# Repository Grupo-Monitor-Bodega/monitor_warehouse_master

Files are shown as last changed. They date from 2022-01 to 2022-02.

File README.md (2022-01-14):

# Sistemas Embebidos
# Monitor Warehouse

* Diego Chaparro

* Juan Diego Carrero

* Raúl Morales

Repositorio del proyecto de la asignatura "Sistemas Embebidos" de la Universidad Nacional de Colombia, sede Bogotá. Aquí encontrará el proyecto del monitor de bodega, con toda la documentación requerida y el diseño completo del mismo.

El proyecto consiste en un monitor que tomará los datos relacionados a la temperatura y humedad en una bodega, en la cual se almacenan granos de café. Para el correcto almacenamiento del café es necesario monitorear los niveles de humedad a los que este se encuentra expuesto, la cual a su vez tiene relación con la temperatura; con base a estos requerimientos, el café requiere que la humedad se encuentre establecida en un rango entre 10.3 y 11.3%, esta a su vez es afectada por las condiciones medioambientales a la que la bodega se encuentra expuesta. El tiempo que duran los bultos de café dentro de la bodega varía dependiendo del tipo, siendo este tiempo de algunos día e incluso puede alcanzar los 10 meses de almacenamiento, en los que se realizan ciertas rotaciones dentro de la bodega.

Se busca que el dispositivo final sea lo más pequeño posible con el fin de facilitar su portabilidad, por otra parte, se requiere que exista la posibilidad de realizar un monitoreo de forma remota y como requerimiento opcional, de realizar a su vez un historial sobre las dos variables a lo largo del tiempo para futuras mejoras en cuanto a la operación de la bodega.

Para la ejecución del proyecto, se realizará primeramente un prototipo funcional haciendo uso de un microcontrolador ESP32, de un sensor Shtc3 de humedad y temperatura, una pantalla lcd, así como de una protoboard y cables necesarios. Una vez el prototipo sea funcional, se realizarán los diseños para la PCB y la caja necesaria para la contención del producto y fácil accesibilidad para el cliente.

Con el fin de realizar alguna revisión posterior al hardware y software, se disponen de dos pines para propósito general.

Por último, en la sección de "Wiki", se amplía la información relacionada con el proyecto.

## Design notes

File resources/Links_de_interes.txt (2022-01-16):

Hoja de datos Sensor SHTC3
https://media.digikey.com/pdf/Data%20Sheets/Sensirion%20PDFs/HT_DS_SHTC3_D1.pdf

Hoja de datos Pantalla OLED 0.91" 128X32 SSD1306
http://www.buydisplay.com/download/manual/ER-OLED0.91-1_Series_Datasheet.pdf

Protocolo pantalla OLED
https://cdn-shop.adafruit.com/datasheets/SSD1306.pdf

Hoja de aplicación cargador batería
http://ww1.microchip.com/downloads/en/AppNotes/01149c.pdf

Aplicación TP4056
https://www.best-microcontroller-projects.com/tp4056.html#Using_3_Components_to_achieve_safe_charging

Hoja de datos módulo micro SD
http://datalogger.pbworks.com/w/file/fetch/89507207/Datalogger%20-%20SD%20Memory%20Reader%20Datasheet.pdf

Hoja de datos regulador LD1117
https://www.st.com/en/power-management/ldl1117.html

Hoja de datos Mosfet canal P BSS84P
https://www.electronicaplugandplay.com/component/edocman/?task=document.viewdoc&id=174&Itemid=

Hoja de datos Mosfet canal N BSS138
https://www.electronicaplugandplay.com/component/edocman/?task=document.viewdoc&id=85&Itemid=

Conexión para la medición del voltaje 
https://en.ovcharov.me/2020/02/29/how-to-measure-battery-level-with-esp32-microcontroller/

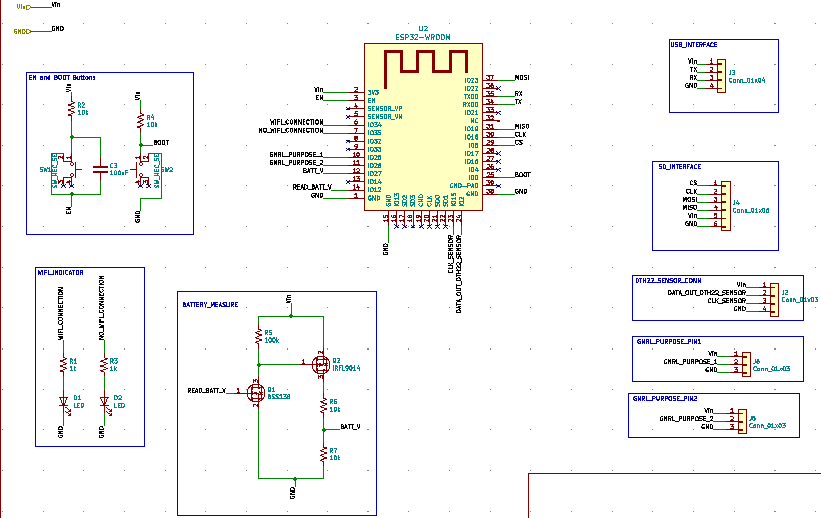
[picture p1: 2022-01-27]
resources/img/FinalSchematic1.png

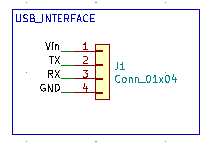
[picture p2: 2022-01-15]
resources/img/Schematic1.png

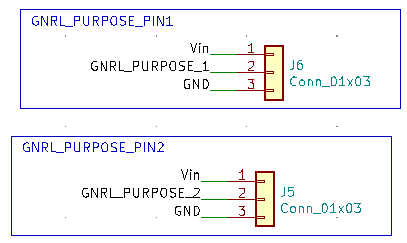
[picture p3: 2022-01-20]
resources/img/Schematic7.png

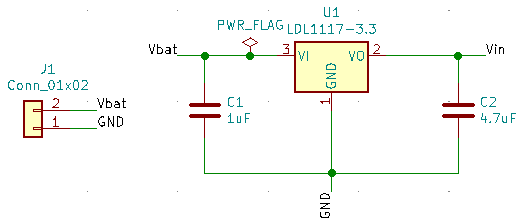
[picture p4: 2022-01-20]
resources/img/Schematic9.png

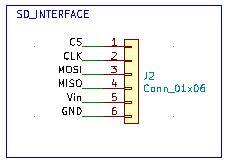
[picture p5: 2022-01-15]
resources/img/Schematic2.png

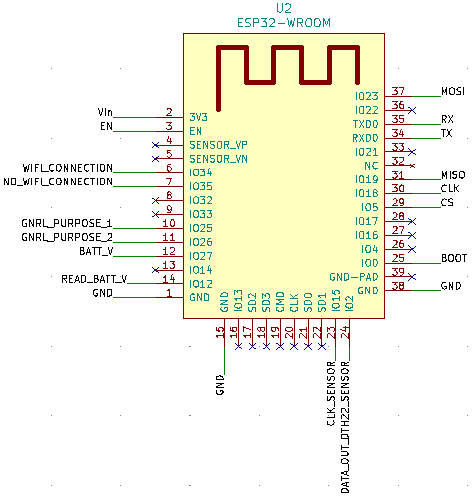
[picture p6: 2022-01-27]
resources/img/Schematic6.png

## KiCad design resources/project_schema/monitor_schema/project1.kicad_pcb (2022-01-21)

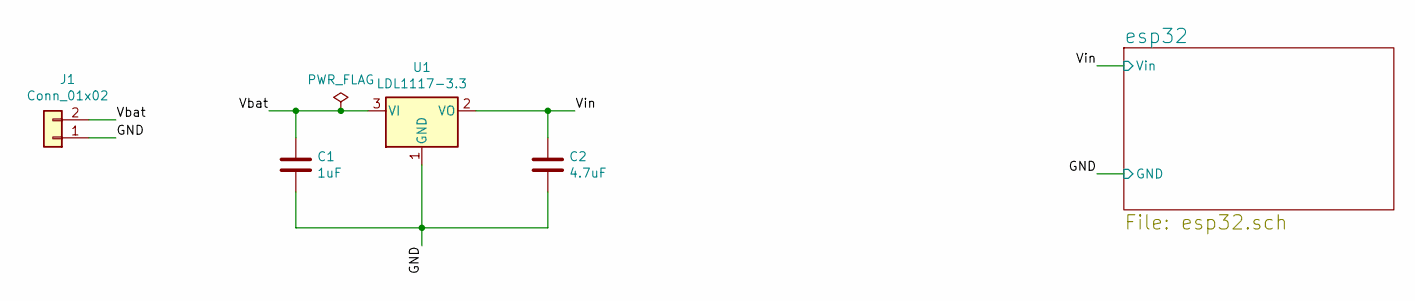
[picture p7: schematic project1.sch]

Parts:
C1: 1uF; C_0805_2012Metric_Pad1.18x1.45mm_HandSolder
C2: 4.7uF; C_0805_2012Metric_Pad1.18x1.45mm_HandSolder
J1: Conn_01x02; PinHeader_1x02_P2.54mm_Vertical
U1: LDL1117-3.3; SOT-223-3_TabPin2

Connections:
/GND: C1.2, C2.2, J1.1, U1.1 (GND); also elsewhere on the board
/Vbat: C1.1, J1.2, U1.3 (VI)
/Vin: C2.1, U1.2 (VO); also elsewhere on the board

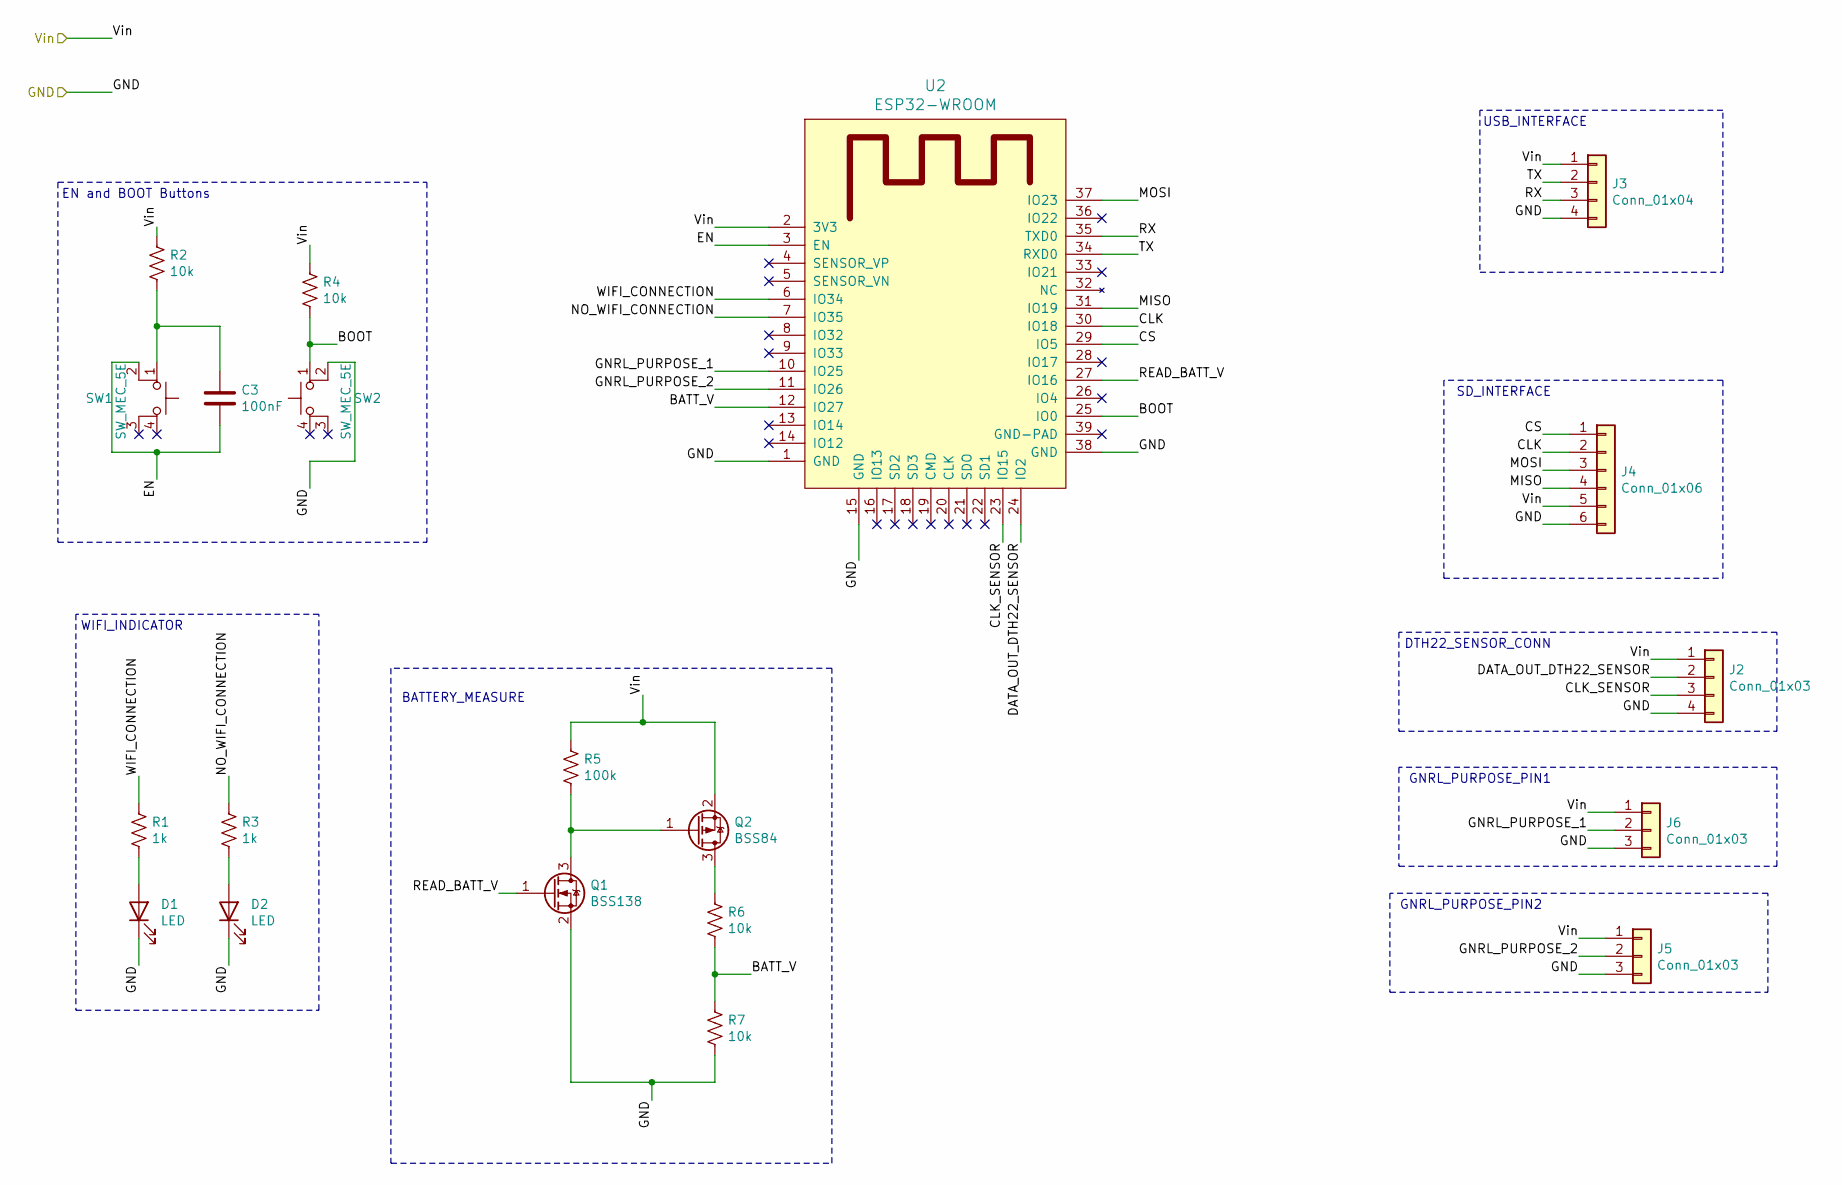
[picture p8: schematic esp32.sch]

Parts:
C3: 100nF; C_0805_2012Metric_Pad1.18x1.45mm_HandSolder
D1, D2: LED; LED_0805_2012Metric_Pad1.15x1.40mm_HandSolder
J2: Conn_01x03; PinHeader_1x04_P2.54mm_Vertical
J3: Conn_01x04; PinHeader_1x04_P2.54mm_Vertical
J4: Conn_01x06; PinHeader_1x06_P2.54mm_Vertical
J5, J6: Conn_01x03; PinHeader_1x03_P2.54mm_Vertical
Q1: BSS138; SOT-23
Q2: BSS84; SOT-23
R1, R3: 1k; R_0805_2012Metric_Pad1.20x1.40mm_HandSolder
R2, R4, R6, R7: 10k; R_0805_2012Metric_Pad1.20x1.40mm_HandSolder
R5: 100k; R_0805_2012Metric_Pad1.20x1.40mm_HandSolder
SW1, SW2: SW_MEC_5E; SW_Push_1P1T_NO_6x6mm_H9.5mm
U2: ESP32-WROOM; ESP32-WROOM-32E

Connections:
/GND: D1.1 (K), D2.1 (K), J2.4, J3.4, J4.6, J5.3, J6.3, Q1.2 (S), R7.2, SW2.2, U2.1 (GND), U2.15 (GND), U2.38 (GND); also elsewhere on the board
/Vin: J2.1, J3.1, J4.5, J5.1, J6.1, Q2.2 (S), R2.1, R4.1, R5.1, U2.2 (3V3); also elsewhere on the board
/esp32/BATT_V: R6.2, R7.1, U2.12 (IO27)
/esp32/BOOT: R4.2, SW2.1, U2.25 (IO0)
/esp32/CLK: J4.2, U2.30 (IO18)
/esp32/CLK_SENSOR: J2.3, U2.23 (IO15)
/esp32/CS: J4.1, U2.29 (IO5)
/esp32/DATA_OUT_DTH22_SENSOR: J2.2, U2.24 (IO2)
/esp32/EN: C3.1, SW1.2, U2.3 (EN)
/esp32/GNRL_PURPOSE_1: J6.2, U2.10 (IO25)
/esp32/GNRL_PURPOSE_2: J5.2, U2.11 (IO26)
/esp32/MISO: J4.4, U2.31 (IO19)
/esp32/MOSI: J4.3, U2.37 (IO23)
/esp32/NO_WIFI_CONNECTION: R3.1, U2.7 (IO35)
/esp32/RX: J3.3, U2.35 (TXD0)
/esp32/TX: J3.2, U2.34 (RXD0)
/esp32/WIFI_CONNECTION: R1.1, U2.6 (IO34)
unnamed: C3.2, R2.2, SW1.1
unnamed: D1.2 (A), R1.2
unnamed: D2.2 (A), R3.2
unnamed: Q1.3 (D), Q2.1 (G), R5.2
unnamed: Q2.3 (D), R6.1

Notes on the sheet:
WIFI_INDICATOR
DTH22_SENSOR_CONN
SD_INTERFACE
USB_INTERFACE
BATTERY_MEASURE
GNRL_PURPOSE_PIN1
GNRL_PURPOSE_PIN2
EN and BOOT Buttons

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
Board: 2 copper layers, 24 parts (0 on the bottom side), 24 nets, no tracks yet.

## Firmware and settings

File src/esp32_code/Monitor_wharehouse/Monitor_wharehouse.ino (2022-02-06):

#include <Arduino.h>
#include "Battery.h";
#include "MicroSd.h";
#include <WiFi.h>

Battery batt;
MicroSd micro;

#define WIFI_SSID "XXXXXX"
#define WIFI_PASSWORD "XXXXXXXX"


unsigned long previousMillis = 0;
const long interval = 10000; //Para que testear sea más sencillo 
//const long interval = 18000000; //Hace la lectura cada 30 min
String filename = "/data.csv";
void setup() {
  // put your setup code here, to run once:
  Serial.begin(115200);
   WiFi.begin(WIFI_SSID, WIFI_PASSWORD);
  Serial.print ("Attempting connection");
  bool wififlag = true;
  while ((WiFi.status() != WL_CONNECTED)&& wififlag) {
    Serial.print(".");
    delay(300); 
    unsigned long currentMillis = millis();
    long wifiwaitingt = 25000;
    if (currentMillis >= wifiwaitingt){
      wififlag = false;
      Serial.println("Can't connect to the network");
    }
  }
  Serial.print("Connected status ");
  if(WiFi.status()==WL_CONNECTED){
    batt.wifiOn();
  }else{
    batt.wifiOff(false);
  }
  int sd_count = 0;
  while(!micro.initSd(filename) && sd_count<5){
    Serial.println("Not SD found");
    delay(300);
    sd_count++;
  }
}

void loop() {
  // put your main code here, to run repeatedly:
  unsigned long currentMillis = millis();
  if (currentMillis - previousMillis >= interval) {
    batt.readBattery();
    previousMillis = currentMillis;
  }
}

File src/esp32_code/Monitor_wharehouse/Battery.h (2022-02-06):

#ifndef Battery_h

#define Battery_h


#include "Arduino.h"


double voltage = 0;

class Battery 
{
  public:
    Battery();
    void readBattery();
    void wifiOn();
    void wifiOff(bool low_bat);
  private:
    int pin_voltage = 27;
    int pin_read = 12;
    int red_led = 35;
    int green_led = 34;    
};

Battery::Battery(){
  pinMode(pin_read,OUTPUT);
  pinMode(red_led,OUTPUT);
  pinMode(green_led,OUTPUT);
  pinMode(pin_voltage,INPUT);
  digitalWrite(pin_read,LOW);
}

void Battery::readBattery(){
  digitalWrite(pin_read,HIGH);
  delay(10);
  voltage = (analogRead(pin_voltage)* 3.3 ) / (4095);
  Serial.println("Voltaje: "+String(voltage));
  delay(10);
  digitalWrite(pin_read,LOW);
}

void Battery::wifiOn(){
  digitalWrite(green_led,HIGH);
  digitalWrite(red_led,LOW);
}

void Battery::wifiOff(bool low_bat){
  if (low_bat){
    digitalWrite(green_led,HIGH);
    digitalWrite(red_led,HIGH);  
  }else{
    digitalWrite(green_led,LOW);
    digitalWrite(red_led,HIGH);  
  }
}

#endif

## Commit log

2021-11-02 Create Datasheet Sensor SHTC3
2021-11-02 Create Datasheet Display Oled 0.91" I2C 128*32 SSD1306
2022-01-11 add esp32 schema kicad
    [project1.kicad_pcb, project1.sch]
2022-01-16 add pwr batt sensor and pwr regulator
    [esp32.sch, project1.sch]
2022-01-18 Update pcb layout
    [esp32.sch, project1.kicad_pcb, project1.sch]
2022-01-19 Pequeña modificación del esquematico
    [project1.kicad_pcb]
2022-01-19 Adelanto de PCB
    [project1.kicad_pcb]
2022-01-19 Modificación PCB por dos caras
    [project1.kicad_pcb]
2022-01-24 PCB layout
    [project1-Juan.kicad_pcb]
2022-01-25 PCB corregida con ancho de vias, corte y sujeción
    [project1-Juan.kicad_pcb, project1-old.kicad_pcb]
2022-01-27 Change pnp transistor footprint
    [esp32.sch, project1-Juan.kicad_pcb]
2022-01-27 Creación del comprimido grb para cotizar
    [project1-Juan-B_Cu.gbr, project1-Juan-B_Mask.gbr, project1-Juan-B_Paste.gbr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]
2022-01-27 PCB images and some changes from schematic
2022-02-06 Add code for programming esp32
